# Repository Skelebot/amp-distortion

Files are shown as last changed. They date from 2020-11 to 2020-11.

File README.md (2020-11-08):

# Micro amp / distortion guitar pedal
Open-source micro amplifier guitar pedal with germanium diode distortion, heavily inspired by [MXR MicroAmp](https://www.jimdunlop.com/mxr-micro-amp/) and [MXR Distortion+](https://www.jimdunlop.com/mxr-distortion/).

## Features:
 - Clean and transparent volume boost with flat frequency response
 - Optional germanium diode signal clipping with a simple ON-ON switch (distortion)
 - True bypass using a 2PDT ON-ON switch
 - Completely un-colored sound, even with distortion on
 - Small board form factor (30mm x 55mm), most THT elements replaced with SMD
 - Smooth type distortion thanks to traditional germanium diodes
 - Wide distortion level range - from very soft to hard and saturated
 - Signal boost up to +34.7dB (54x voltage gain)
 - Designed to be powered by a 9V center-negative power adapter, but can be powered with up to 20V
 - Extremely low noise - uses a TL071 op-amp instead of more noisy TL061 (MicroAmp) or LM741 (Distortion+) amps
 - Can be easily fitted to smaller enclosures than both MXR MicroAmp and MXR Distortion+ (min. case size around 35 x 85mm)

## Customizing

 - **No distortion**: Do not install D2, D3 and SW1. Replace RV2 with a standard 10k resistor across its outer terminals
 - **Log pot instead of reverse-log**: Note that the middle pad of RV1 is not traced, so you can connect a standard logarithmic potentiometer backwards. Please note that when using a non-reverse-log potentiometer backwards, gain control will be reversed - the knob will have to be turned counter-clockwise to increase gain.
 - **On/Off LED**: The pedal does not have an on/off LED, which allows it to have true bypass with a 2PDT switch instead of a more expensive 3PDT switch. If you have a 3PDT switch, connect a LED+resistor to the leftover 3 terminals of the switch. Refer to [this image](https://mike-bland.com/images/3pdt-wiring.png) for a wiring diagram.
 - **Silicon diodes**: You can use standard silicon diodes (f.e. 1N4148) instead of germanium ones, but keep in mind that they usually have a much higher forward voltage - because of insufficient gain the pedal may not be able to create as much distortion, or may distort the sound only when the gain potentiometer is set to maximum.
 - **Different diodes**: Keep an eye on the diodes' forward voltage - it should be between 0.1 and 0.5V (±0.05V). The lower it is, the more distortion you will get. The pedal was tested with DOG35 and AAZ15 germanium diodes (Vf = 0.46V and 0.21 respectively) - distortion from the former was much less noticeable.

## BOM

|Ref |Quantity|Value |Description |
|---|---|---|---|
|C1 |1 |1uF |SMD Capacitor, package 0603 (1608 metric) |
|C2, C4  |2 |47pF |SMD Capacitor, package 0603 (1608 metric) |
|C3 |1 |100nF |SMD Capacitor, package 0603 (1608 metric) |
|C5 |1 |10uF |SMD Capacitor, package 0603 (1608 metric) |
|D1 |1 |minimum 30V |12.70mm THT Schottky diode |
|D2, D3  |2 |Vf = 0.1V to 0.5V|THT germanium diode |
|J1 |1 |- |6.35mm THT audio jack (mono or stereo) |
|J2 |1 |- |DC Barrel jack |
|J3 |1 |- |6.35mm THT audio jack (mono or stereo) |
|R1 |1 |22M |THT resistor |
|R2 |1 |2.7K |SMD resistor, package 0805 (2012 metric) |
|R3, R4  |2 |100K |SMD resistor, package 0805 (2012 metric) |
|R5 |1 |10M |THT resistor |
|R6 |1 |1K |SMD resistor, package 0805 (2012 metric) |
|R7 |1 |150K |SMD resistor, package 0805 (2012 metric) |
|R8 |1 |470 |SMD resistor, package 0805 (2012 metric) |
|RV1 |1 |500K |Reverse-logarithmic 500K potentiometer (C500K)|
|RV2 |1 |10K |Linear 10K potentiometer (B10K) |
|SW1 |1 |- |SPST ON-ON switch |
|U1 |1 |TL071 |TL071 op-amp, SO8 Package |
|- |1 |- |DPDT ON-ON foot switch (not on schematic) |

## Making one yourself:

The board is single-sided and designed with loose tolerances between pads/traces for easy home-etching. I did not pay attention to the silkscreen, so if you want one fabricated remember to generate gerber files without it. Order boards without plated holes.
There are 5 bridges to be made on the board:
 - Between two holes over R8
 - Between two holes over R6
 - Between two closest terminals of R6 and C3
 - Between the center (negative) terminal of the DC jack and the copper pad left of D2/D3 (on the bottom of the board) 
 - Between the negative terminal of the DC jack and the closer ends of R4/C1
Refer to the brd file for a better view.
RV1, RV2 and the switches are soldered to the board with cables (not directly) so they can be mounted to the case independently.
The DPDT switch connections are described on the schematic (pad symbols are positioned as if you were looking on the bottom of the switch)
For the case, you can buy a universal enclosure of your choosing (make sure the board fits) and drill holes in it yourself, or print case.stl on a 3D printer.

#### *Made exclusively with open source tools*

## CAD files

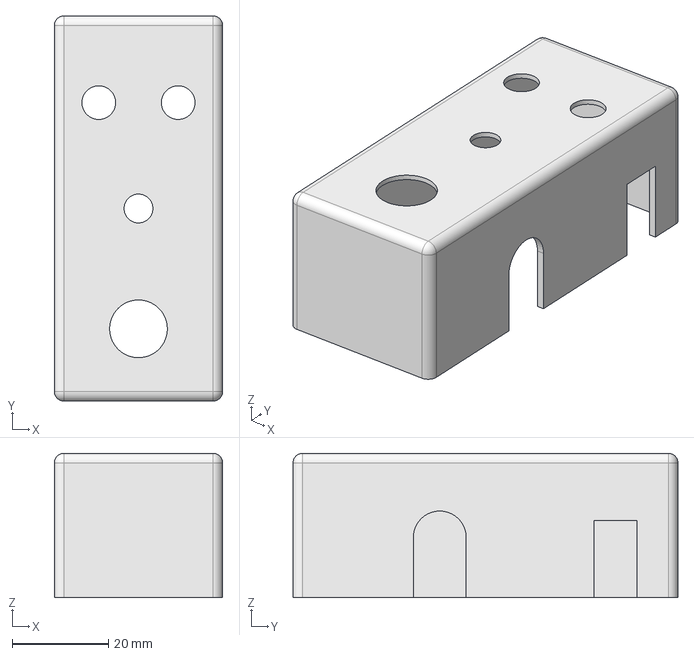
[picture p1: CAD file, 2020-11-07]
case/case.FCStd
35.0 x 80.0 x 30.0 mm

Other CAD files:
case/case.stl

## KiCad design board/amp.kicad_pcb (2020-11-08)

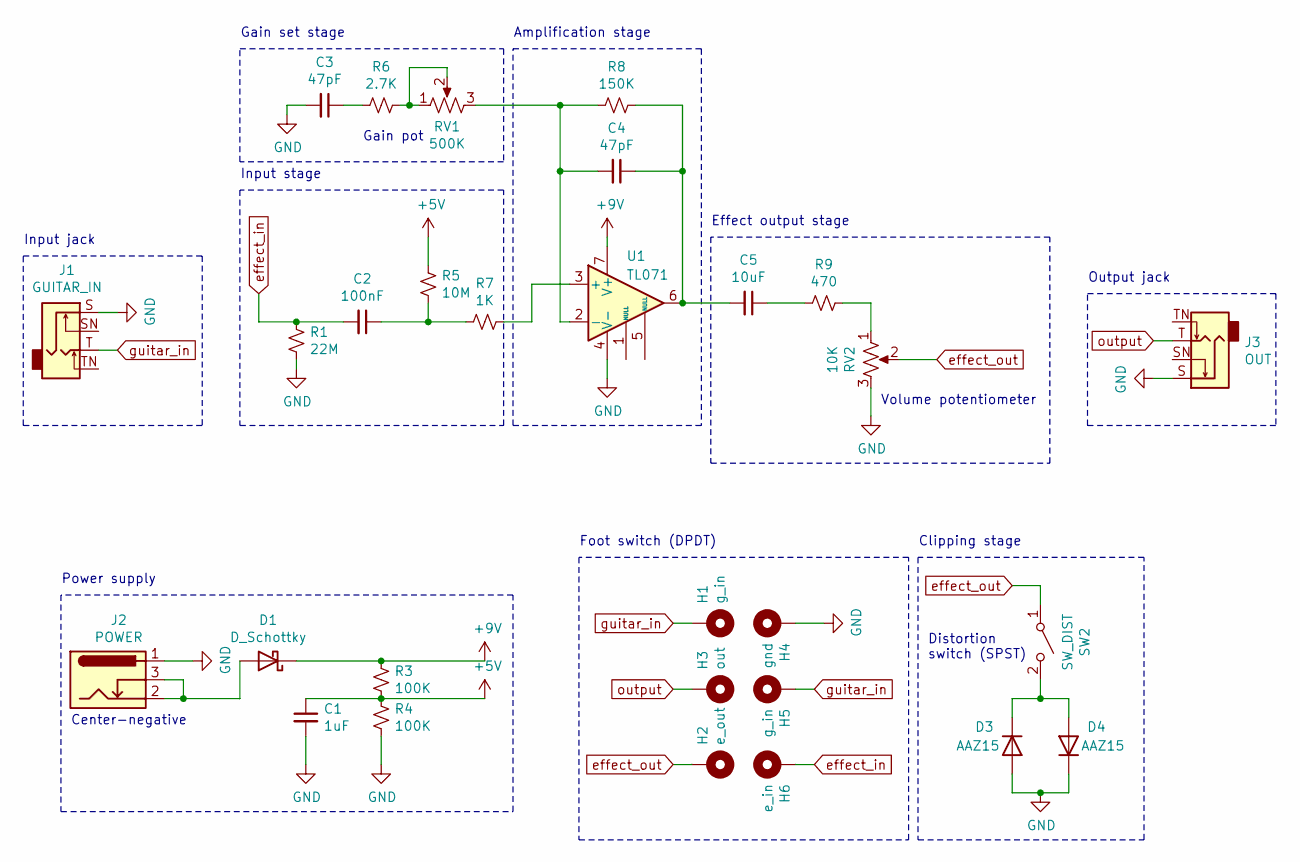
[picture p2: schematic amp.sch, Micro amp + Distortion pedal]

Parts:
C1: 1uF; C_0603_1608Metric
C2: 100nF; C_0603_1608Metric
C3, C4: 47pF; C_0603_1608Metric
C5: 10uF; C_0603_1608Metric
D1: D_Schottky; D_DO-15_P12.70mm_Horizontal
D3, D4: AAZ15; D_DO-35_SOD27_P12.70mm_Horizontal
H1, H5: g_in; TestPoint_Pad_D2.0mm
H2: e_out; TestPoint_Pad_D2.0mm
H3: out; TestPoint_Pad_D2.0mm
H4: gnd; TestPoint_Pad_D2.0mm
H6: e_in; TestPoint_Pad_D2.0mm
J1: GUITAR_IN; Jack_6.35mm_Neutrik_NRJ6HM-1-AU_Horizontal
J2: POWER; BarrelJack_Horizontal
J3: OUT; Jack_6.35mm_Neutrik_NRJ6HM-1-AU_Horizontal
R1: 22M; R_Axial_DIN0411_L9.9mm_D3.6mm_P12.70mm_Horizontal
R3, R4: 100K; R_0805_2012Metric_Pad1.15x1.40mm_HandSolder
R5: 10M; R_Axial_DIN0207_L6.3mm_D2.5mm_P7.62mm_Horizontal
R6: 2.7K; R_0805_2012Metric_Pad1.15x1.40mm_HandSolder
R7: 1K; R_0805_2012Metric_Pad1.15x1.40mm_HandSolder
R8: 150K; R_0805_2012Metric_Pad1.15x1.40mm_HandSolder
R9: 470; R_0805_2012Metric_Pad1.15x1.40mm_HandSolder
RV1: 500K; PinSocket_1x03_P2.54mm_Vertical
RV2: 10K; PinSocket_1x03_P2.54mm_Vertical
SW2: SW_DIST; PinSocket_1x02_P2.54mm_Vertical
U1: TL071; SO-8_5.3x6.2mm_P1.27mm

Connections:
+5V: C1.1, R3.2, R4.1, R5.1
+9V: D1.1 (K), R3.1, U1.7 (V+)
GND: C1.2, C3.2, D3.2 (A), D4.1 (K), H4.1, J1.S, J2.1, J3.S, R1.2, R4.2, RV2.3, U1.4 (V-)
unnamed: C2.1, R5.2, R7.2
unnamed: C3.1, R6.2
unnamed: C4.1, C5.2, R8.1, U1.6
unnamed: C4.2, R8.2, RV1.3, U1.2 (-)
unnamed: C5.1, R9.2
unnamed: D1.2 (A), J2.2, J2.3
unnamed: D3.1 (K), D4.2 (A), SW2.2 (B)
unnamed: R6.1, RV1.1, RV1.2
unnamed: R7.1, U1.3 (+)
unnamed: R9.1, RV2.1
effect_in: C2.2, H6.1, R1.1
effect_out: H2.1, RV2.2, SW2.1 (A)
guitar_in: H1.1, H5.1, J1.T
output: H3.1, J3.T

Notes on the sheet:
Clipping stage
Volume potentiometer
Gain pot
Power supply
Effect output stage
Input stage
Amplification stage
Gain set stage
Foot switch (DPDT)
Distortion switch (SPST)
Input jack
Output jack
Center-negative

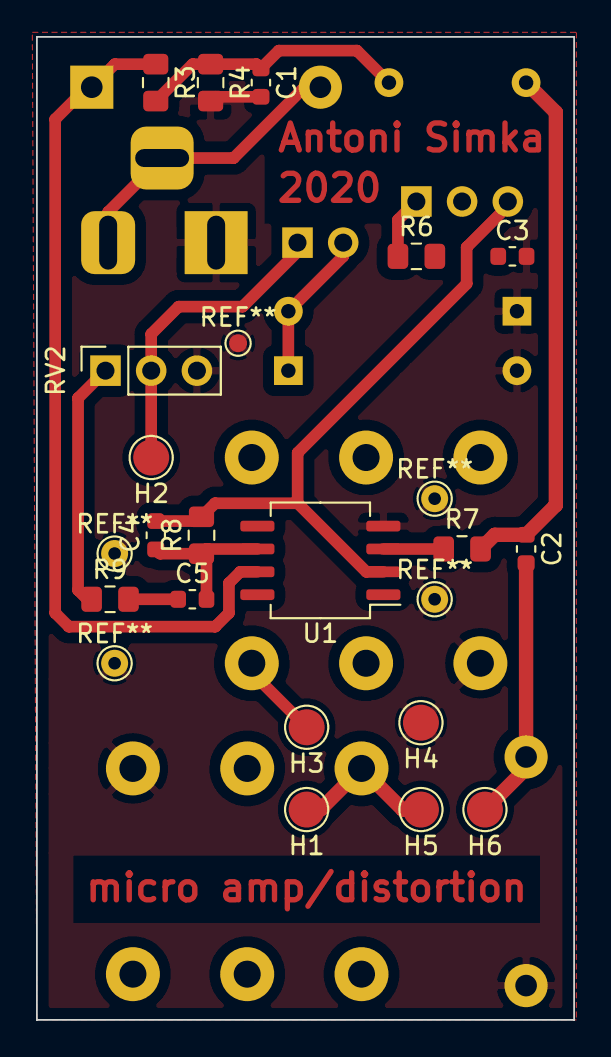
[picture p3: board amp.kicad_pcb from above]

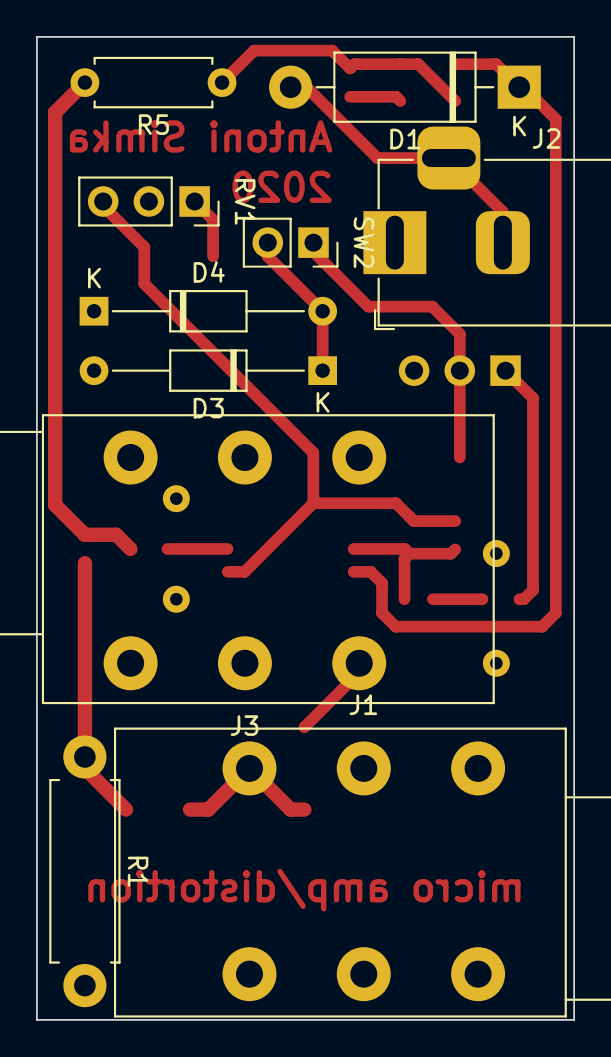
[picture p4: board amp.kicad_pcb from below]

Board: 2 copper layers, 29.8 x 54.6 mm, 29 parts (10 on the bottom side), 17 nets.

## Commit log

2020-11-07 Add schematic and board files rev v2
    [amp.kicad_pcb, amp.sch]
2020-11-07 Add case 3D model
    [case.FCStd, case.stl]
2020-11-07 Add BOM CSV
    [bom.csv]
2020-11-08 Fix board, README corrections
    Reverse power jack polarity (make it center-negative), fix typos and
    other mistakes in README
    [amp.kicad_pcb, amp.sch]
